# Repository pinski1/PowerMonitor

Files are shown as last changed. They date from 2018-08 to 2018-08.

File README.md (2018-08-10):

# Power Monitor
I wanted to monitor the current and voltage of some battery packs as I discharged them. As the battery packs were >36V fully charged there was no available board to do this easily. So here's one that's good for up to 80V.

This project is an entry into the [Hackaday.io](Hackaday.io) [Square Inch Project](https://hackaday.io/contest/160135-the-return-of-the-square-inch-project) Contest.

## Detailed Description

This project makes use of the Analog Devices [LTC4151](http://www.analog.com/en/products/monitor-control-protection/power-monitors/ltc4151.html) to measure the voltage, current and communicate these values over an I<sup>2</sup>C bus. In addition the LTC4151 will also calculate the instantaneous power and read an auxilary ADC input, in my board I've set this to be a temperature sensor.

### I<sup>2</sup>C Address
By default the I<sup>2</sup>C address is set to 0xD4 but if you wish to change it please consult this table:

|JP1|JP2|Address|
|----|----|----|
|X|X|0xCC|
|L|H|0xCE|
|H|NC|0xD0|
|H|H|0xD2|
|NC|NC|0xD4|
|L|NC|0xD6|
|H|L|0xD8|
|NC|H|0xDA|
|NC|L|0xDC|
|L|L|0xDE|

### Registers

|Register Address|Register Name|Read/Write|Description|
|--|--|--|--|
|0x00|SENSE (A)|R/W|ADC Current Sense Voltage Data (8 MSBs)|
|0x01|SENSE (B)|R/W|ADC Current Sense Voltage Data (4 LSBs)|
|0x02|VIN (C)|R/W|ADC VIN Voltage Data (8 MSBs)|
|0x03|VIN (D)|R/W|ADC VIN Voltage Data (4 LSBs)|
|0x04|ADIN (E)|R/W|ADC ADIN Voltage Data (8 MSBs)|
|0x05|ADIN (F)|R/W|ADC ADIN Voltage Data (4 LSBs)|
|0x06|CONTROL(G)|R/W|Controls ADC Operation Mode and Test Mode|
|0x07-0xFF|Reserved|N/A|Remaining addresses reserved|

Note: Registers A-F are only writeable if bit G4 is set.

### Calculating Current

+7V to +80V input range
81.92mV V_sense maximum
0R002 => 40.96A maximum
0R002 3.2W resistor 

### Calculating Temperature
[Thermistor](http://uk.farnell.com/panasonic-electronic-components/ertj1vs104fa/thermistor-ntc-0603-100k/dp/1892612)

## Licence
<br />This work is licensed under a <a rel="license" href="http://creativecommons.org/licenses/by-sa/4.0/">Creative Commons Attribution-ShareAlike 4.0 International License</a>.

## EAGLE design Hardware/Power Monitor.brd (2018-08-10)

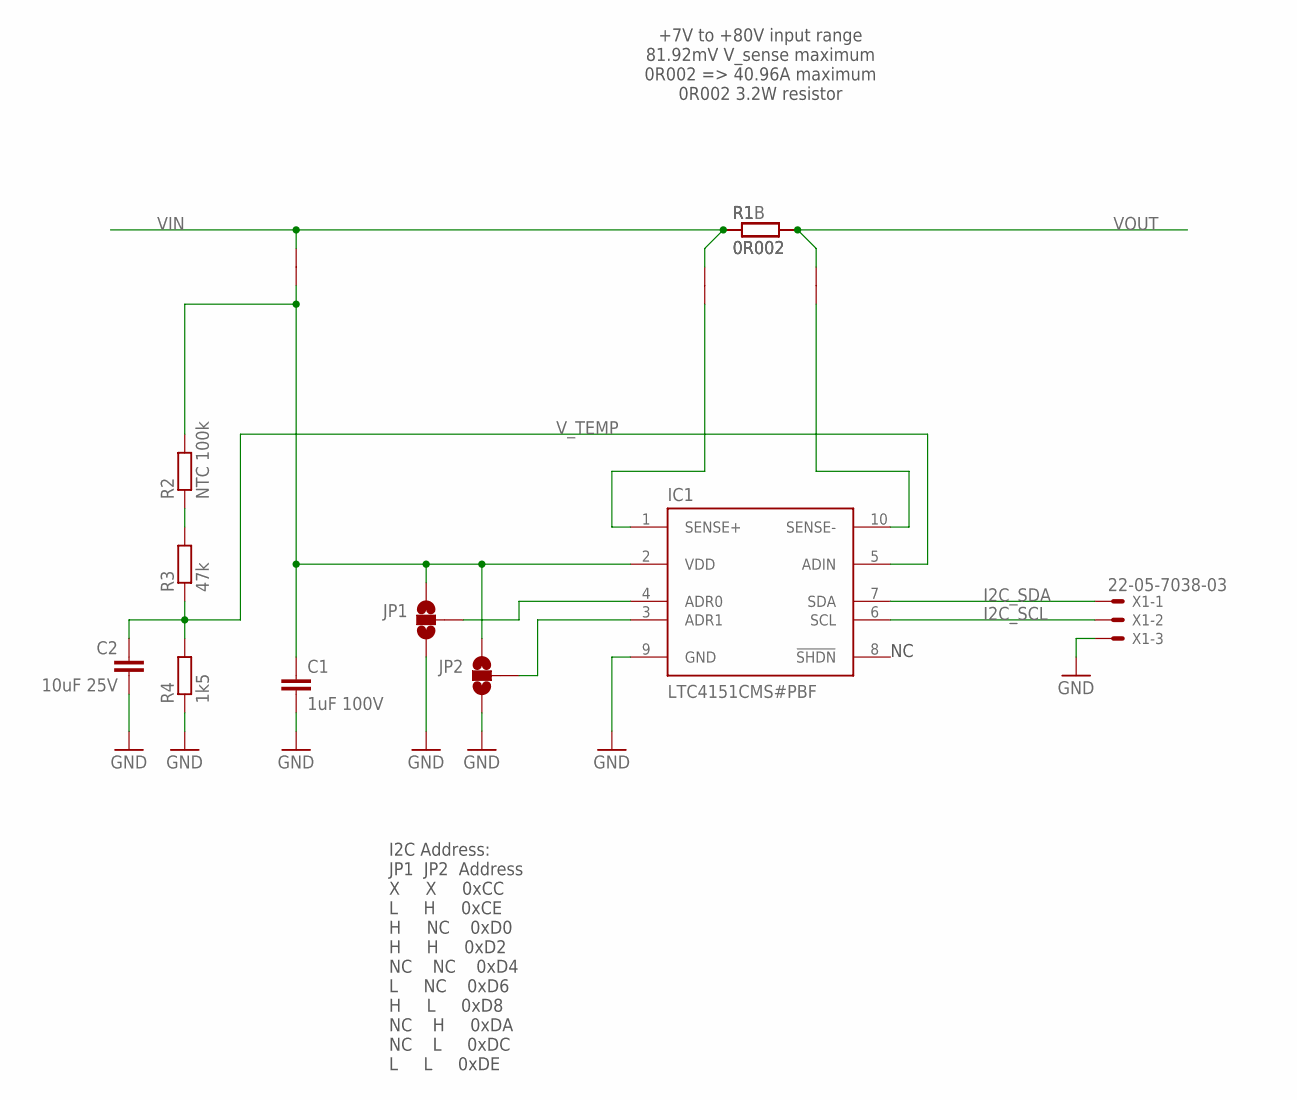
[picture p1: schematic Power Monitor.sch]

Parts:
C1: 1uF 100V; C0603
C2: 10uF 25V; C0603
IC1: LTC4151CMS#PBF; MSOP10
JP1, JP2: JUMPER-SMT_3_NO_SILK; SMT-JUMPER_3_NO_SILK
R1, R1B: 0R002; R2512; FARNELL_OC 2709404
R2: NTC 100k; R0603
R3: 47k; R0603
R4: 1k5; R0603
U$2, U$3, U$4: SHORT-002; 2X2
X1: 22-05-7038-03; 7395-03

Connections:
GND: C1.2, C2.2, IC1.9 (GND), JP1.3, JP2.3, R4.1, X1.3
I2C_SCL: IC1.6 (SCL), X1.2
I2C_SDA: IC1.7 (SDA), X1.1
unnamed: IC1.4 (ADR0), JP1.2
unnamed: IC1.3 (ADR1), JP2.2
unnamed: R2.1, R3.2
SEN_N: IC1.10 (SENSE-), U$3.1
SEN_P: IC1.1 (SENSE+), U$2.1
VDD: C1.1, IC1.2 (VDD), JP1.1, JP2.1, R2.2, U$4.1
VIN: R1.1, R1B.1, U$2.2, U$4.2
VOUT: R1.2, R1B.2, U$3.2
V_TEMP: C2.1, IC1.5 (ADIN), R3.1, R4.2

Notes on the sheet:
+7V to +80V input range 81.92mV V_sense maximum 0R002 => 40.96A maximum 0R002 3.2W resistor
I2C Address: JP1 JP2 Address X X 0xCC L H 0xCE H NC 0xD0 H H 0xD2 NC NC 0xD4 L NC 0xD6 H L 0xD8 NC H 0xDA NC L 0xDC L L 0xDE

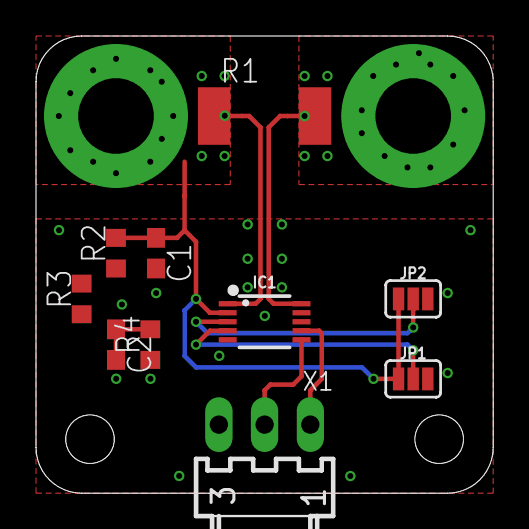
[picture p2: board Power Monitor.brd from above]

Board: 2 copper layers, 25.4 x 25.4 mm, 14 parts (1 on the bottom side), 12 nets.

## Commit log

2018-08-09 Create Power Monitor.sch
    [Power Monitor.sch]
2018-08-09 Create Power Monitor.brd
    [Power Monitor.brd]
2018-08-10 Initial schematic & board checkin.
    [Power Monitor.brd, Power Monitor.sch]

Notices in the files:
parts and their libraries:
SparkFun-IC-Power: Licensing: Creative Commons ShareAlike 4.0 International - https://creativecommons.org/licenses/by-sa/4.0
